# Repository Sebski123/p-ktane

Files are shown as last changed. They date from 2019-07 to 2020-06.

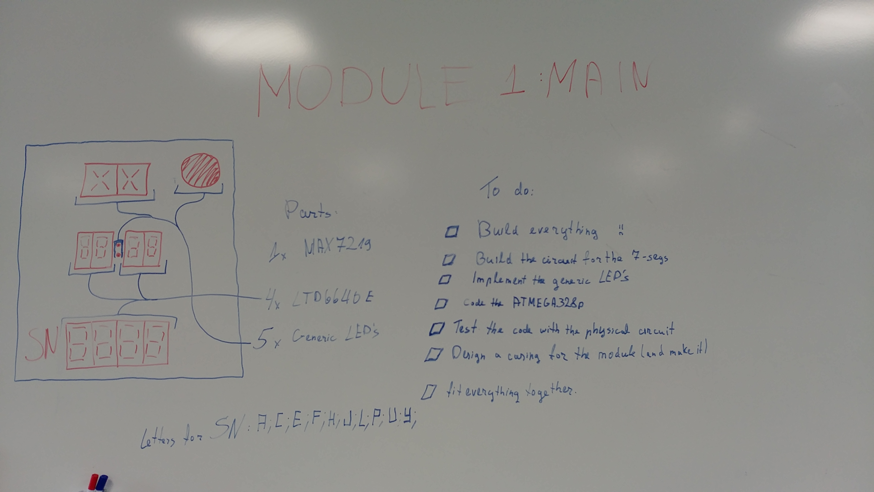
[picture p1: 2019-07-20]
Modules/mainModule/mainModule.jpg

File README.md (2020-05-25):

# P-KTANE
## Sources
* https://github.com/dlareau/KTANE-physical
* https://imgur.com/gallery/J6HdM0v
* https://old.reddit.com/r/ktane/comments/a3fgyt/i_made_a_physical_version_of_the_video_game_keep/
* https://github.com/jgillick/avr-discobus

## Modules
| Module | Coded | Built | Tested | I2C addr |
|---|---|---|---|---|
| Main (Controller) | ✔️ | | | MASTER |
| Config (ESP8266) | ✔️ | ✔️ | ✔️ | 2 |
| [Wires](https://i.imgur.com/xLXpCYH.png) | ✔️ | ✔️ | ✔️ | 3 |
| [Button](https://i.imgur.com/Leew7du.png) | ✔️ | | | 4 |
| [Keypads](https://i.imgur.com/Zy6ScEo.png) | | | | |
| [Simon Says](https://i.imgur.com/uX7BzED.png) | ✔️ | ✔️ | | 5 |
| [Who's on First](https://i.imgur.com/YisE1go.png) | | | | |
| [Memory](https://i.imgur.com/bvGt5gz.png) | ✔️ | ✔️ | | 6 |
| [Morse Code](https://i.imgur.com/V4XAdVZ.png) | | | | |
| [Complicated Wires](https://i.imgur.com/jJb2Kp9.png) | | | | |
| [Wire Sequences](https://i.imgur.com/1drzKTO.png) | | | | |
| [Mazes](https://i.imgur.com/xXMdvLr.png) | ✔️ | ✔️ | ✔️ | 7 |
| [Passwords](https://i.imgur.com/us0XRBs.png) | ✔️ | | | |
| [Venting Gas](https://i.imgur.com/f2eua3p.png) | | | | |
| [Capacitor Discharge](https://i.imgur.com/Q0VJkoo.png) | | | | |
| [Knobs](https://i.imgur.com/hlpkEUD.png) | | | | |

# How to burn bootloader and upload sketches for ATMega328
## How to burn bootloader
### Install boards
1. Open the Arduino IDE.
1. Open the **File > Preferences** menu item.
1. Enter the following URL in **Additional Boards Manager URLs**:

    ```
    https://mcudude.github.io/MiniCore/package_MCUdude_MiniCore_index.json
    ``` 

1. Open the **Tools > Board > Boards Manager...** menu item.
1. Wait for the platform indexes to finish downloading.
1. Scroll down until you see the **MiniCore** entry and click on it.
1. Click **Install**.
1. After installation is complete close the **Boards Manager** window.
1. **Note**: If you plan to use the *PB series, you need the latest version of the Arduino toolchain. This toolchain is available through IDE 1.8.6 or newer. Here's how you install/enable the toolchain:
  -  Open the **Tools > Board > Boards Manager...** menu item.
  -  Wait for the platform indexes to finish downloading.
  -  The top is named **Arduino AVR boards**. Click on this item.
  -  Make sure the latest version is installed and selected
  -  Close the **Boards Manager** window.

### Prepare Arduino
1. Copy [this](https://raw.githubusercontent.com/adafruit/ArduinoISP/master/ArduinoISP.ino) code into the Arduino IDE and upload it to an Arduino normally.
1. Connect Arduino to the ATMega as shown below (Capacitor is important).


### Burn bootloader
1. Select the **Tools > Board > ATmega328** menu item from the MiniCore section.
1. Select the **Tools > Variant > 328 / 328A** menu item.
1. Select the **Tools > Clock > Internal 8MHz** menu item.
1. Select the **Tools > Programmer > Arduino as ISP** menu item.
1. Click **Tools > Burn Bootloader**

## How to upload sketches
### Wiring
1. Remove ATmega328 from Arduino
1. Connect Arduino to the ATMega as shown below.


### Uploading
1. Select the **Tools > Board > ATmega328** menu item from the MiniCore section.
1. Select the **Tools > Variant > 328 / 328A** menu item.
1. Select the **Tools > Clock > Internal 8MHz** menu item.
1. Select the **Tools > Programmer > Arduino as ISP** menu item.
1. Click Upload.

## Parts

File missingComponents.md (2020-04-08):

- Pinheaders-4 x6
- Pinheaders-5 x6
- Pins-4 x6
- 100nF Cap x8
- 10uF Pol Cap x2
- 24.5k Res x4
- Big 7-segment x2
- 0.1 uF Cap x2
- Max7219 x4
- Simon says button x4
- 10k Res x13
- 1k Res x6
- ATMEGA328 x6
- Double 7-segment x6
- 330 Res x21
- RGB LEDs x7
- Push-Buttons x12
- Single pin-header x12
- Green LED x42
- Red LED x4 
- Big transparent button (3D-print)
- Keyboard switches x~5
- Small speaker
- 16-segment x7

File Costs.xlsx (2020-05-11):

Item | Url | Cost | Payee
Transparent 3D-printing filament | https://www.computersalg.dk/i/1127597/verbatim-gennemsigtig-1-kg-abs | 196 | Sebastian
Digikey Order | http://www.digikey.dk | 415.95 | Sebastian
Digikey Order Import Tax | http://www.digikey.dk | 104 | Sebastian
AliExpress simon says switches | https://www.aliexpress.com/item/32833573067.html?spm=a2g0s.9042311.0.0.412d4c4dSjG8y1 | 116 | Sebastian
Total paid by Sebastian: | 831.95
Total paid by Laurynas: | 0
 |  | 415.975 | PAID

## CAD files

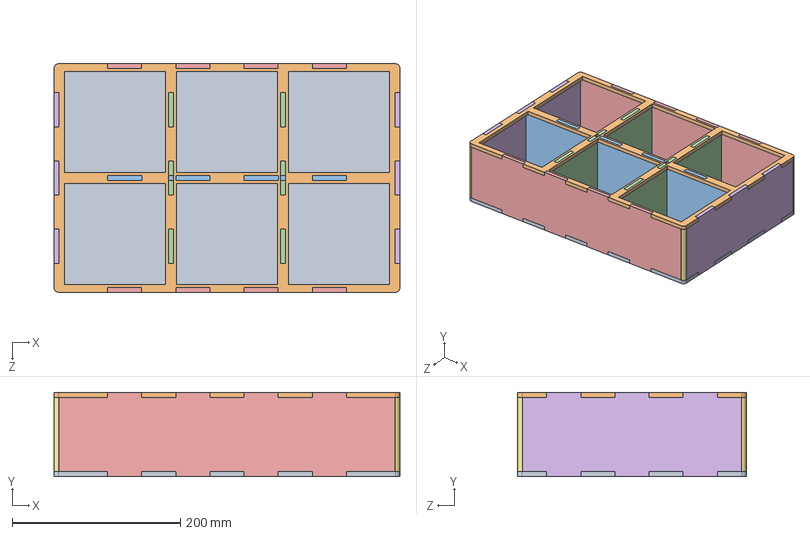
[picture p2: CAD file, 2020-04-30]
Design/Box/Box.SLDASM
410.8 x 100.0 x 271.4 mm
BoxBottom
BoxTop
InsideLarge
InsideSmall x 2
SidesLarge x 2
SidesSmall x 2
Corner x 4

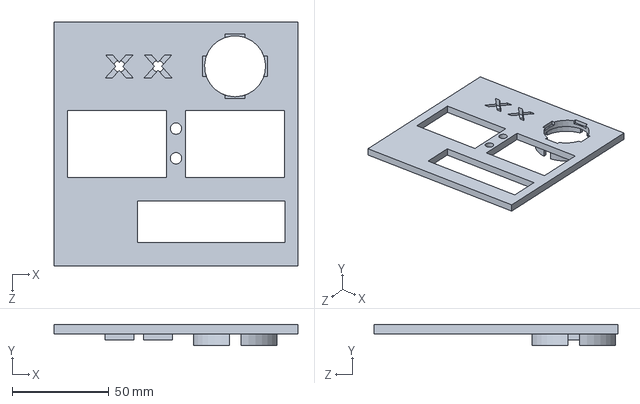
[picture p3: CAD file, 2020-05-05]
Modules/mainModule/Main face plate.SLDPRT
126.0 x 11.0 x 126.0 mm

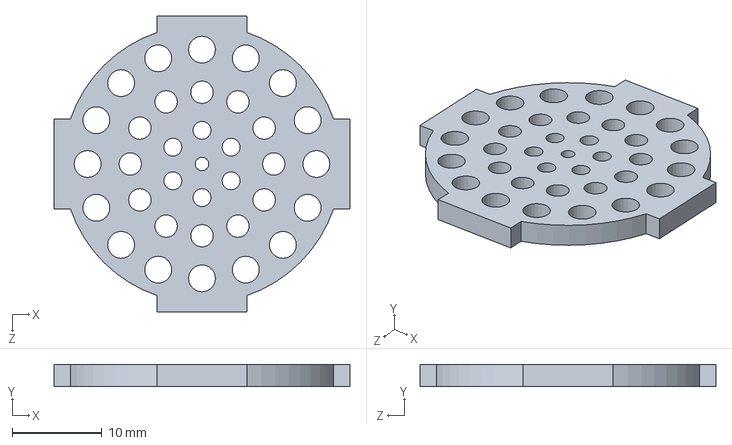
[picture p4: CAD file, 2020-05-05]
Modules/mainModule/Main face plate grill.SLDPRT
33.0 x 2.50 x 33.0 mm

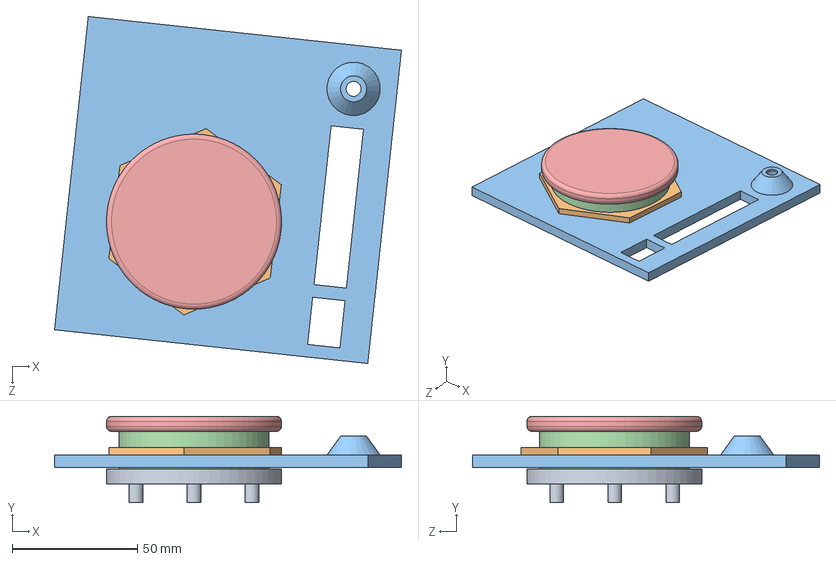
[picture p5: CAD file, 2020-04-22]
Modules/buttonModule/ButtonAssembly.SLDASM
138.8 x 34.5 x 138.8 mm
Button base
Button face plate ring
Button face plate
Button middle
Button top

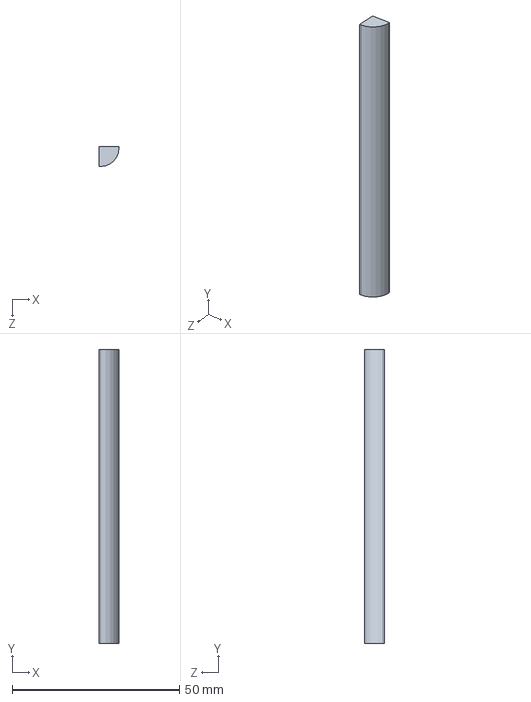
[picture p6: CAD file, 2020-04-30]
Design/Box/Box parts/Corner.SLDPRT
6.00 x 88.0 x 6.00 mm

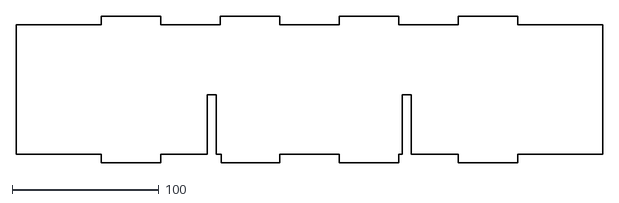
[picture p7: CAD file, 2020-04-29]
Design/Box/DXF FILES/InsideLarge.dxf
398.7 x 100.0

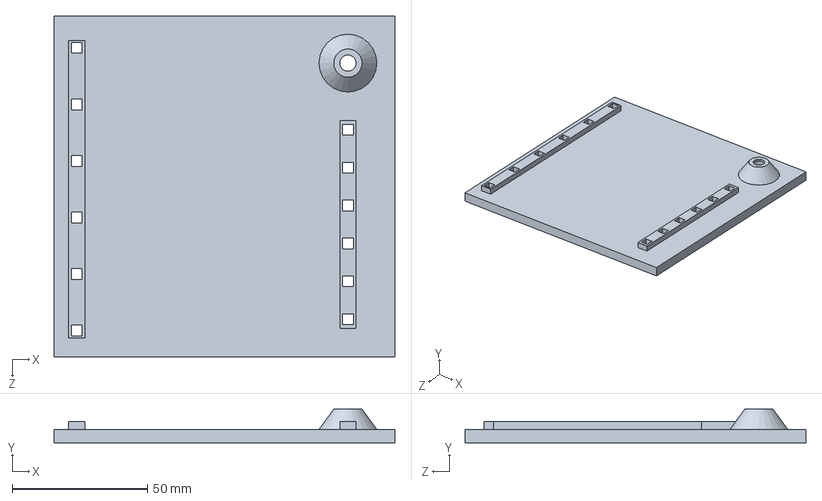
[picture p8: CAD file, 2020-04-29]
Modules/basicWiresModule/Wire face plate.SLDPRT
126.0 x 12.5 x 126.0 mm

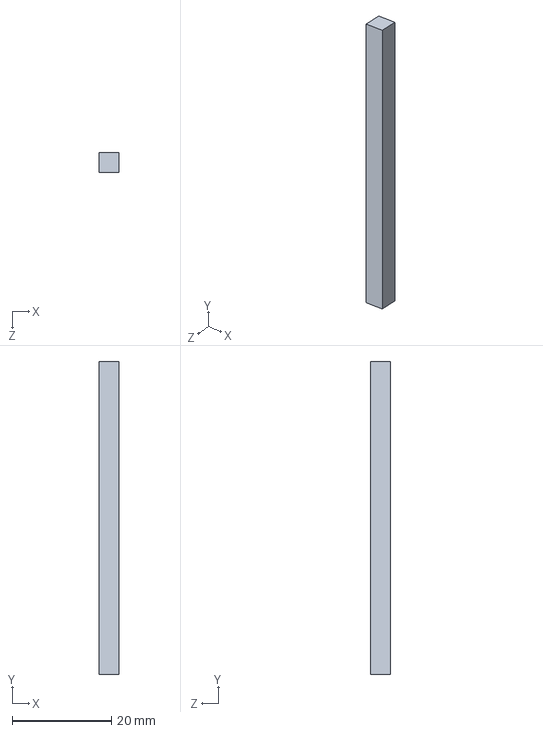
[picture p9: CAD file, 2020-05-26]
Modules/buttonModule/MXFramePillar.SLDPRT
4.00 x 63.0 x 4.00 mm

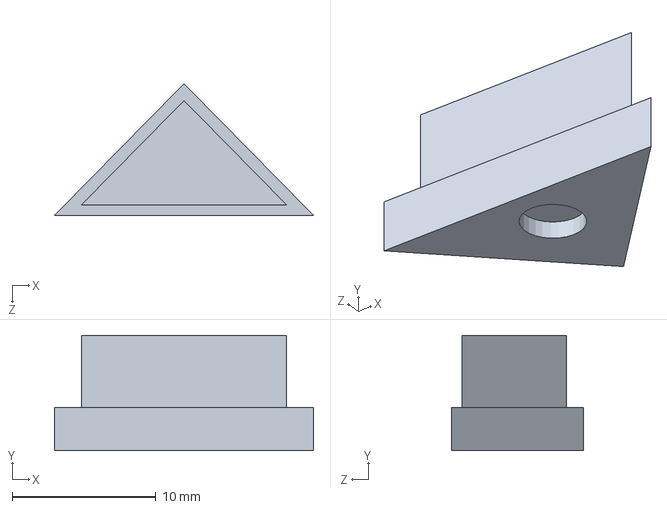
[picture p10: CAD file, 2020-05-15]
Modules/mazeModule/Maze button.SLDPRT
18.0 x 8.00 x 9.15 mm

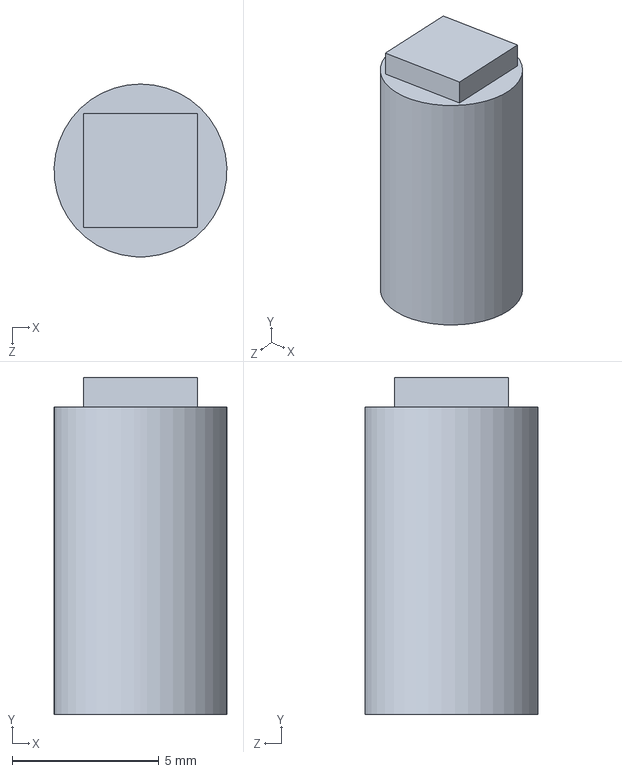
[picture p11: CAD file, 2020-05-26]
Modules/memoryModule/Memory button top.SLDPRT
5.90 x 11.5 x 5.90 mm

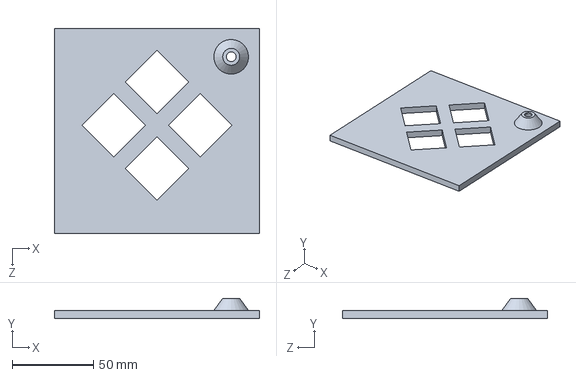
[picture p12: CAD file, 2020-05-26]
Modules/simonSaysModule/Simon says face plate.SLDPRT
126.0 x 12.5 x 126.0 mm

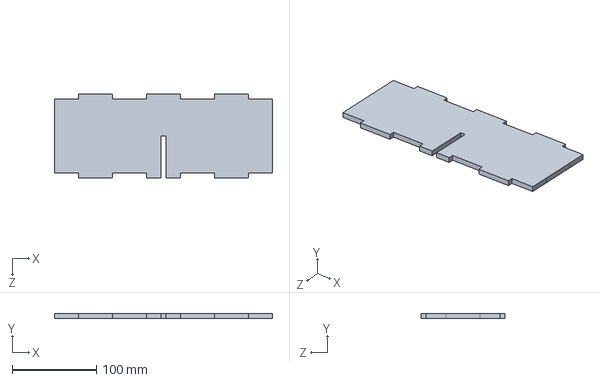
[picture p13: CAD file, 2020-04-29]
Design/Box/Box parts/InsideSmall.SLDPRT
259.4 x 6.00 x 100.0 mm

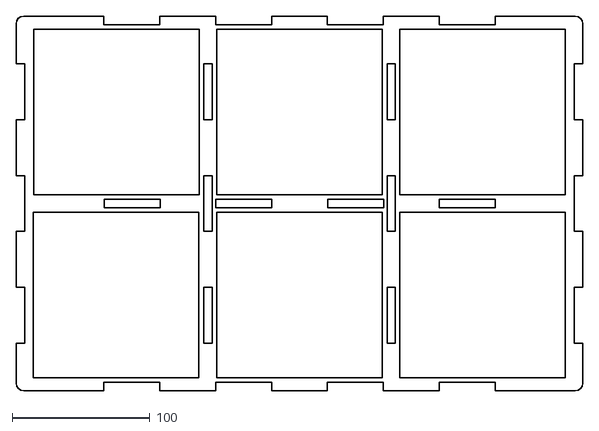
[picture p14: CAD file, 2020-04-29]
Design/Box/DXF FILES/BoxTop.dxf
410.7 x 271.4

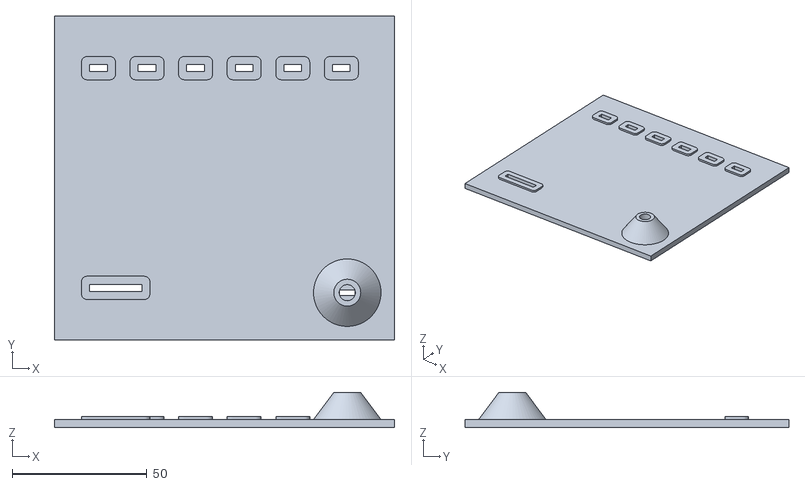
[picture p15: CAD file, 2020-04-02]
Modules/basicWiresModule/front_plate_wires.stl
126.0 x 120.0 x 13.0

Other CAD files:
Modules/buttonModule/MXFrameBottom.SLDPRT
Modules/mazeModule/Maze face plate.SLDPRT
Modules/memoryModule/TRIANGLE.SLDPRT
Modules/simonSaysModule/front_plate_simon.stp
Design/Box/Box parts/BoxBottom.SLDPRT
Design/Box/Box parts/BoxTop.SLDPRT
Design/Box/Box parts/InsideLarge.SLDPRT
Design/Box/Box parts/SidesLarge.SLDPRT
Design/Box/Box parts/SidesSmall.SLDPRT
Design/Box/DXF FILES/BoxBottom.dxf
Design/Box/DXF FILES/InsideSmall.dxf
Design/Box/DXF FILES/SidesLarge.dxf
Design/Box/DXF FILES/SidesSmall.dxf
Modules/buttonModule/Button base.SLDPRT
Modules/buttonModule/Button face plate ring.SLDPRT
Modules/buttonModule/Button face plate side bar.SLDPRT
Modules/buttonModule/Button face plate.SLDPRT
Modules/buttonModule/Button middle.SLDPRT
Modules/buttonModule/Button top.SLDPRT
Modules/buttonModule/MXFrameTop.SLDPRT
Modules/buttonModule/MXSwitchLegs.SLDPRT
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

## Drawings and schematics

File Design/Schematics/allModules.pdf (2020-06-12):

C5 R⁴ | R³ | R² | R¹ | R⁵

# 5 CN8 R⁴⁹

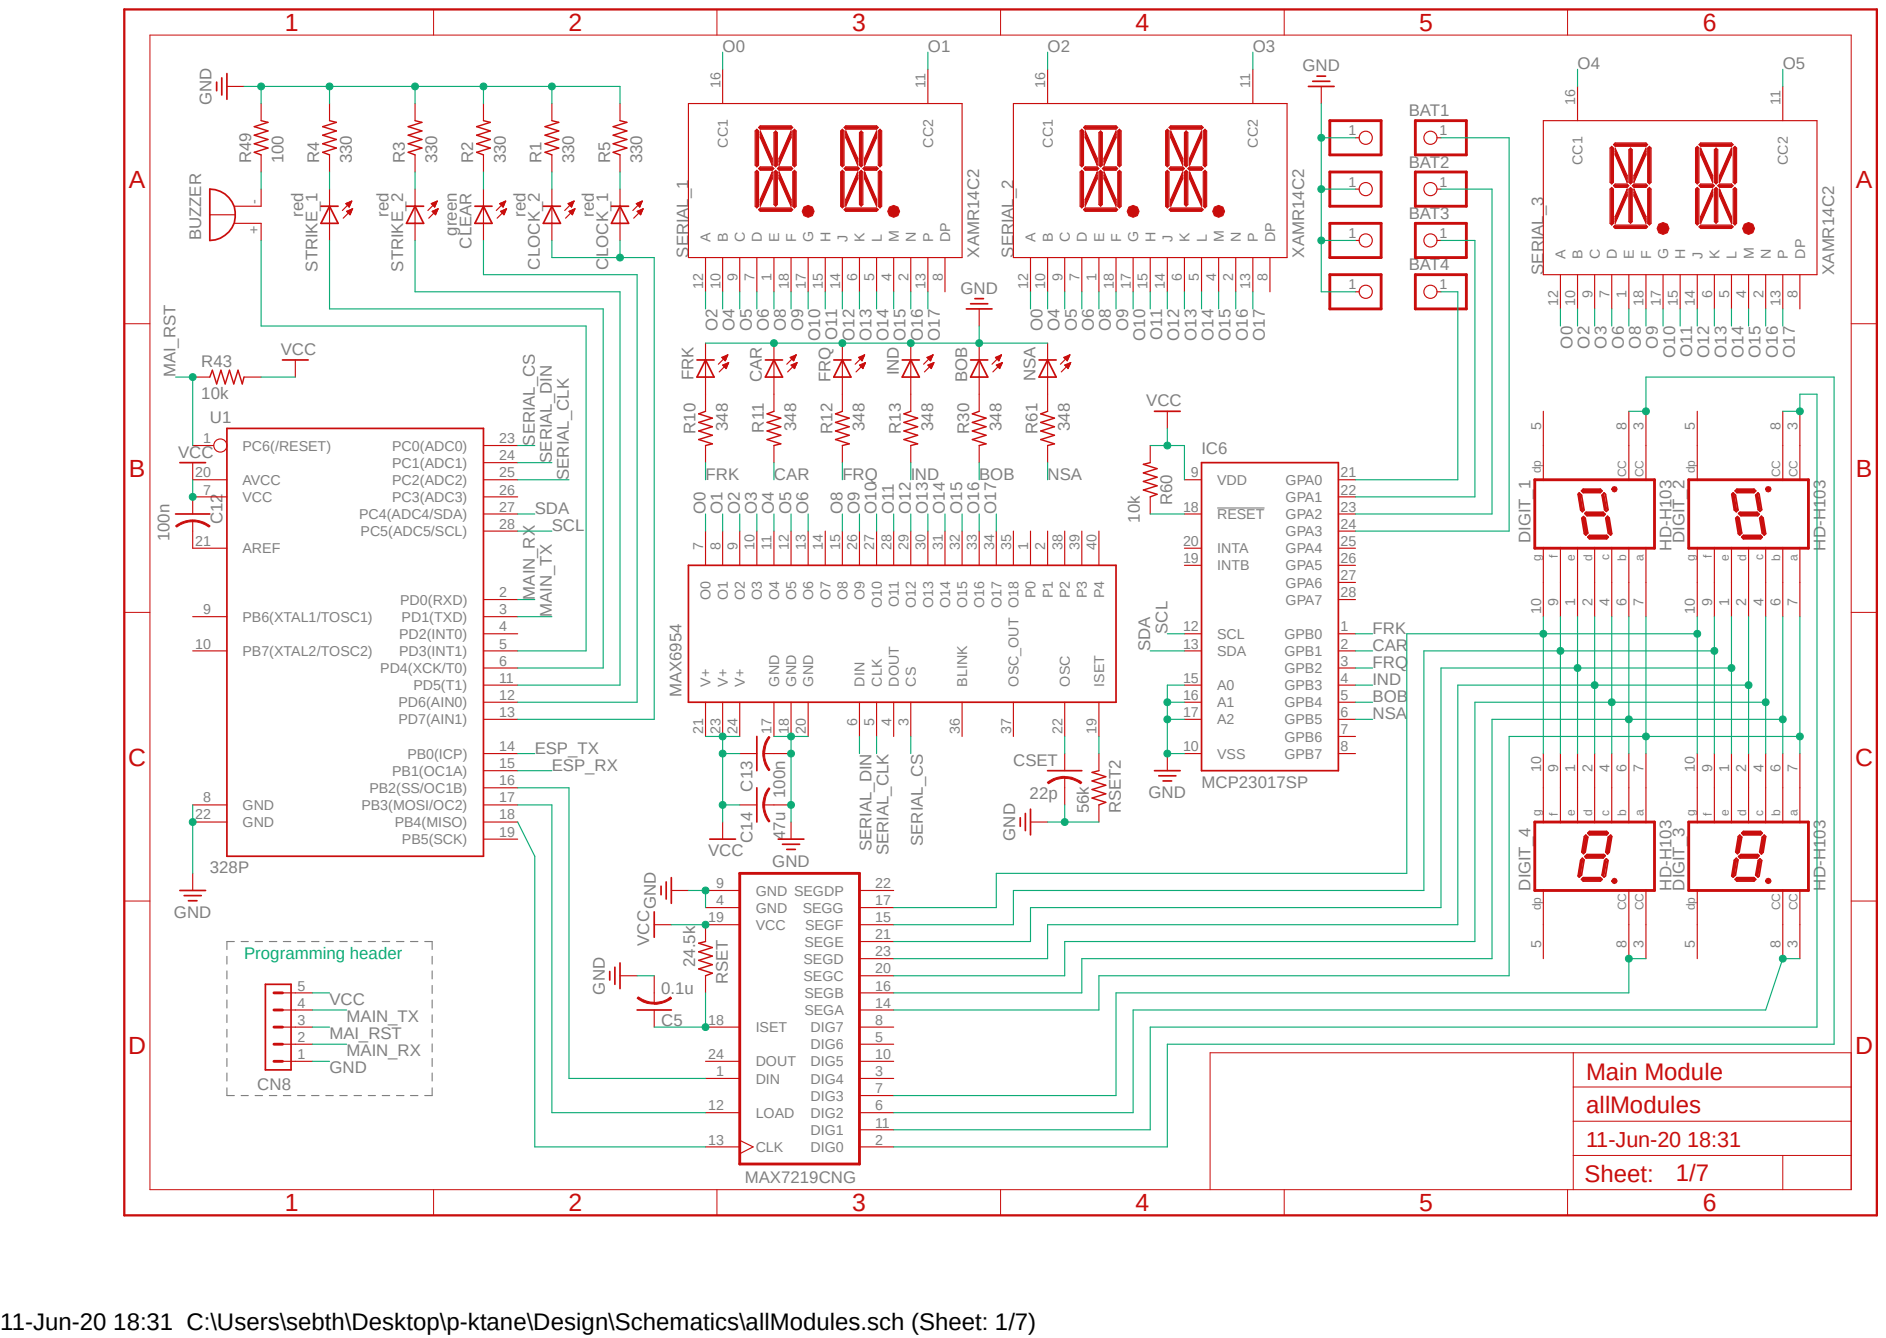
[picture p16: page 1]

11-Jun-20 18:31 C:\Users\sebth\Desktop\p-ktane\Design\Schematics\allModules.sch (Sheet: 1/7)

A

A

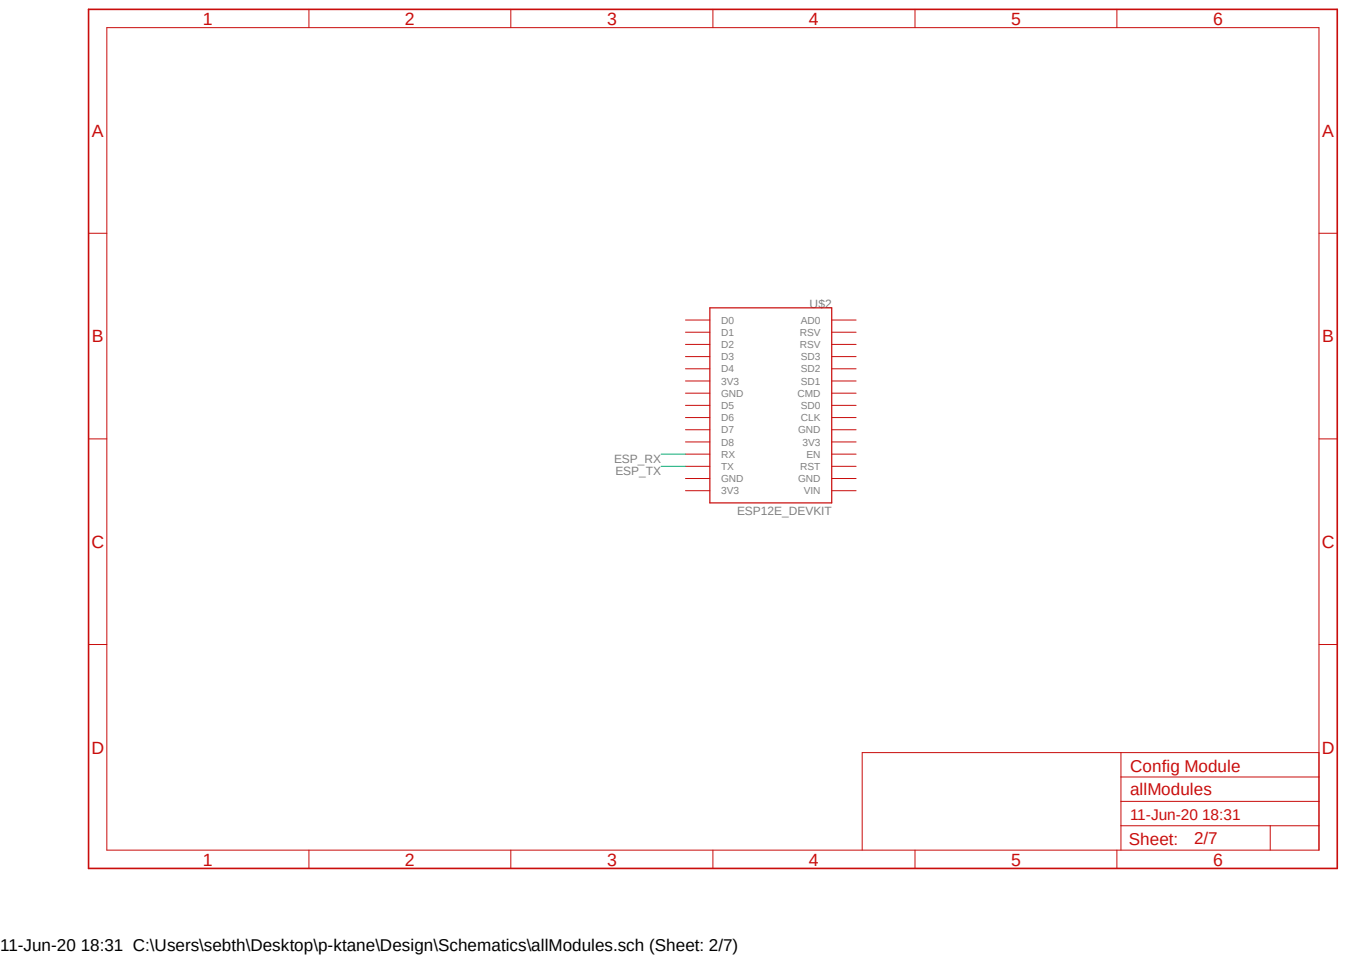
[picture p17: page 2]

11-Jun-20 18:31 C:\Users\sebth\Desktop\p-ktane\Design\Schematics\allModules.sch (Sheet: 2/7)

A

A

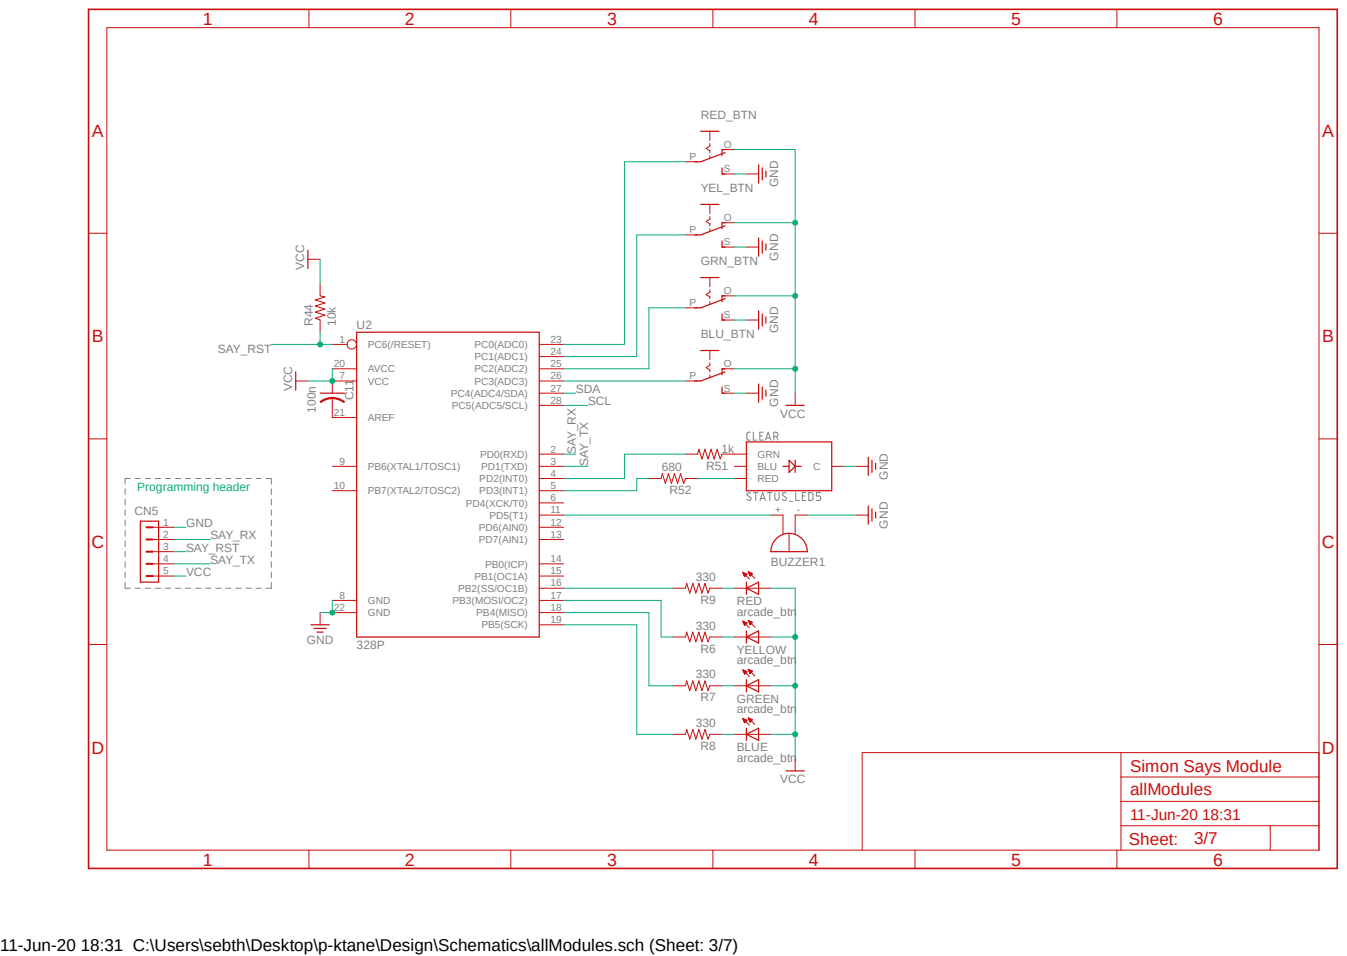
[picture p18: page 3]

arcade_btn GND GND GND GNDVCC

11-Jun-20 18:31 C:\Users\sebth\Desktop\p-ktane\Design\Schematics\allModules.sch (Sheet: 3/7)

GND 1k | 680
5 CN4 C¹⁰ R⁴⁵ | GRN BLU C RED R⁵³ | R⁵⁴

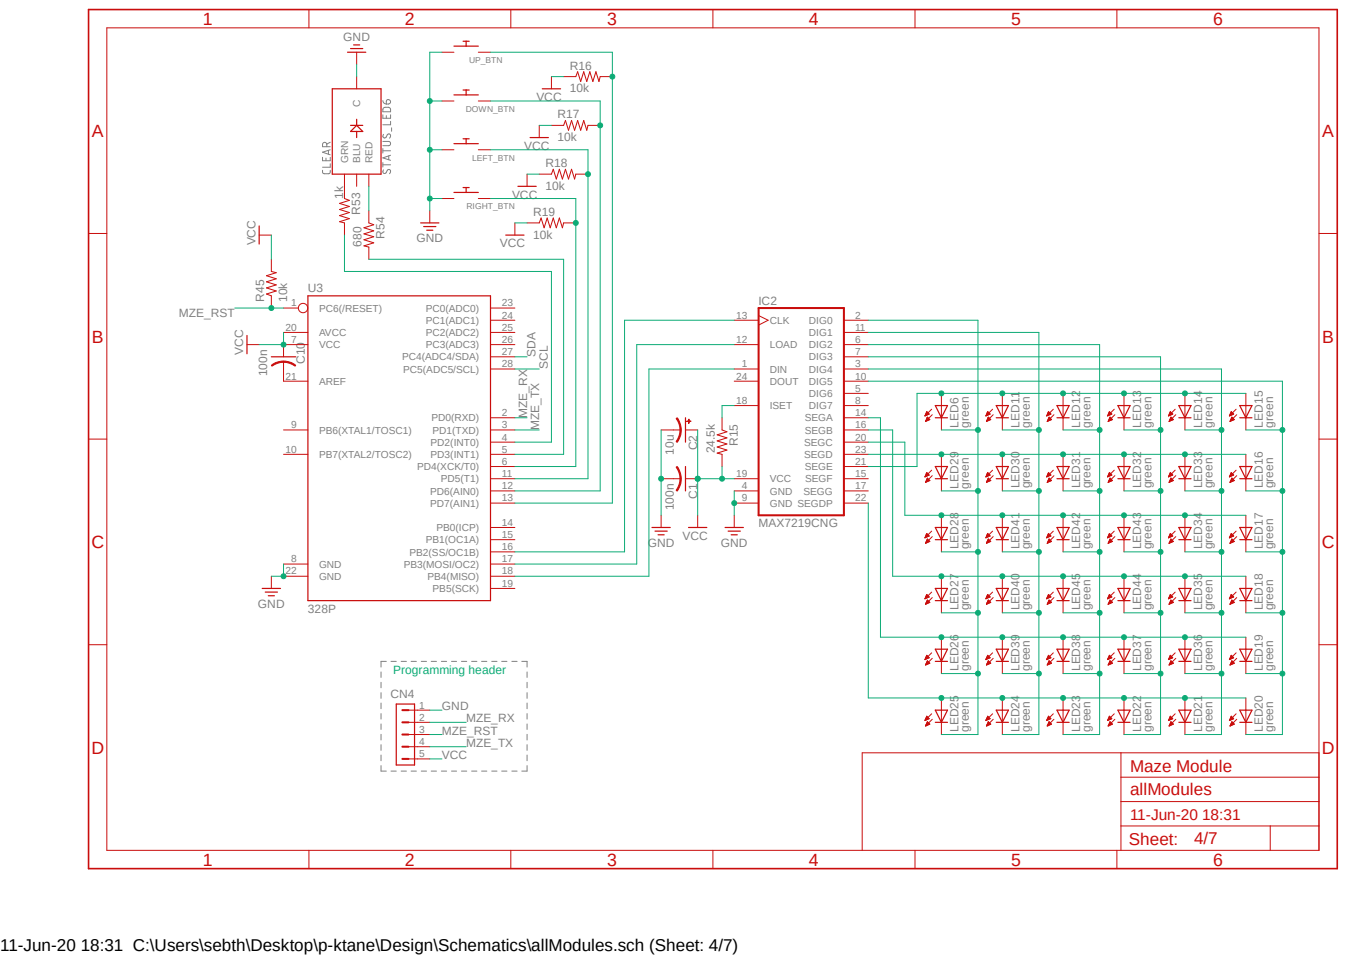
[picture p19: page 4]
MAX7219CNG; GND; GND VCC VCC; VCC; green; green green green green green green green green green green; green green; green green green green green green; green 100n; 10k VCC; DIG2; DIG3; DIG4; DIG5; DIG6; DIG7; SEGA; SEGB; SEGC; SEGD; SEGE; SEGF; SEGG; SEGDP; DIG1; 11 DIG0; DIN 1 DOUT 24; LOAD 12; CLK 13; ISET 18; GND 9; GND 4; VCC 19; PB5(SCK); PB7(XTAL2/TOSC2) 10; PB6(XTAL1/TOSC1) 9; GND 8 GND 22; VCC 7; AREF 21; AVCC 20; PB4(MISO); 18 PB3(MOSI/OC2); 15 PB0(ICP); PD7(AIN1); 13 PD6(AIN0)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

11-Jun-20 18:31 C:\Users\sebth\Desktop\p-ktane\Design\Schematics\allModules.sch (Sheet: 4/7)

# 5 CN3 R⁴⁶

# SW_TX SW_RST

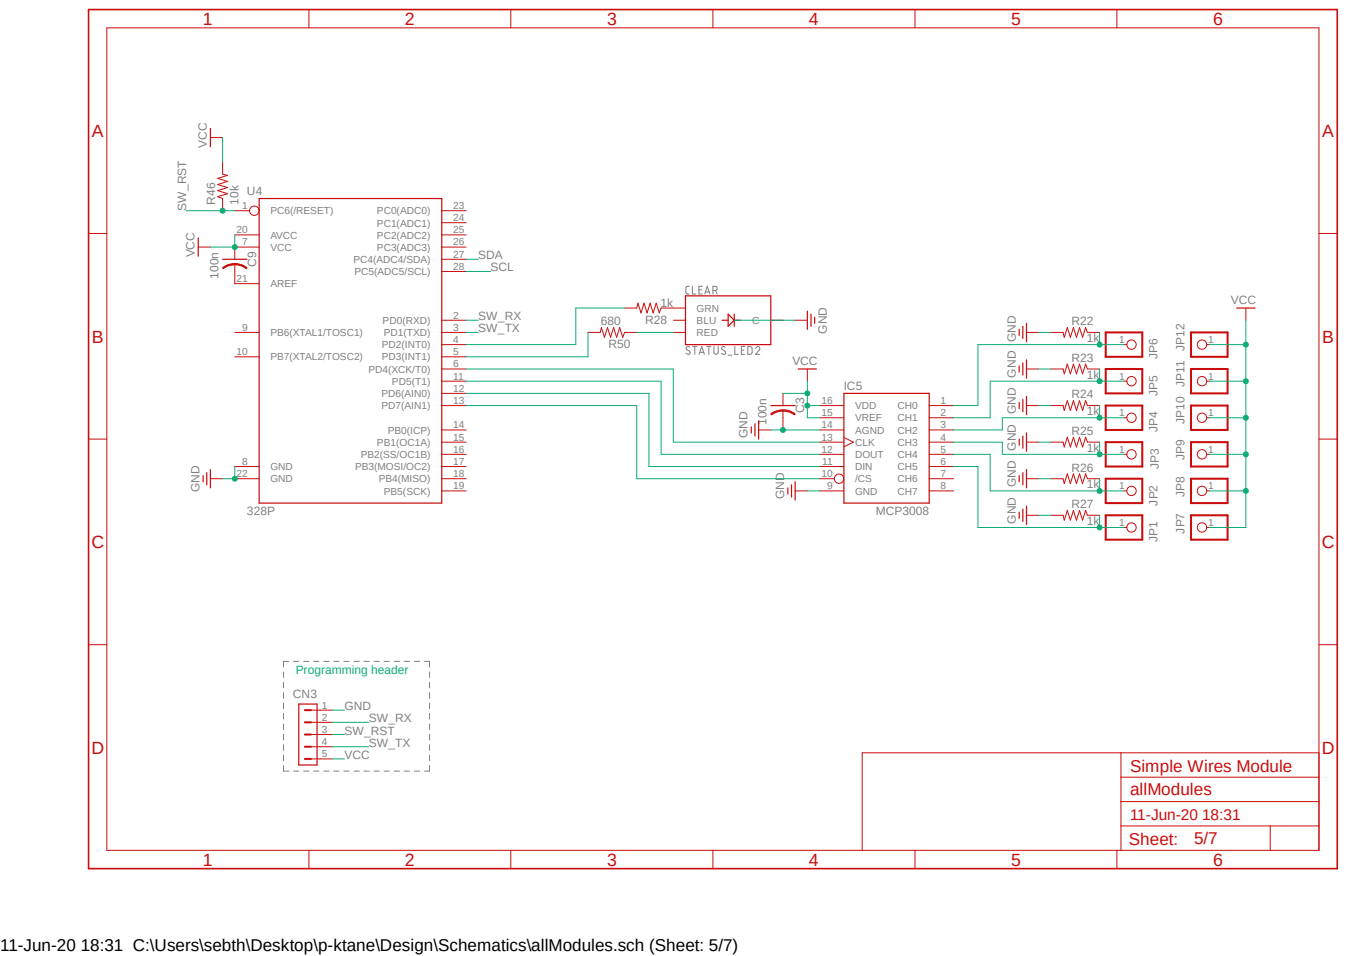
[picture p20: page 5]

11-Jun-20 18:31 C:\Users\sebth\Desktop\p-ktane\Design\Schematics\allModules.sch (Sheet: 5/7)

# 5 CN2 C⁸ R⁴⁷

A

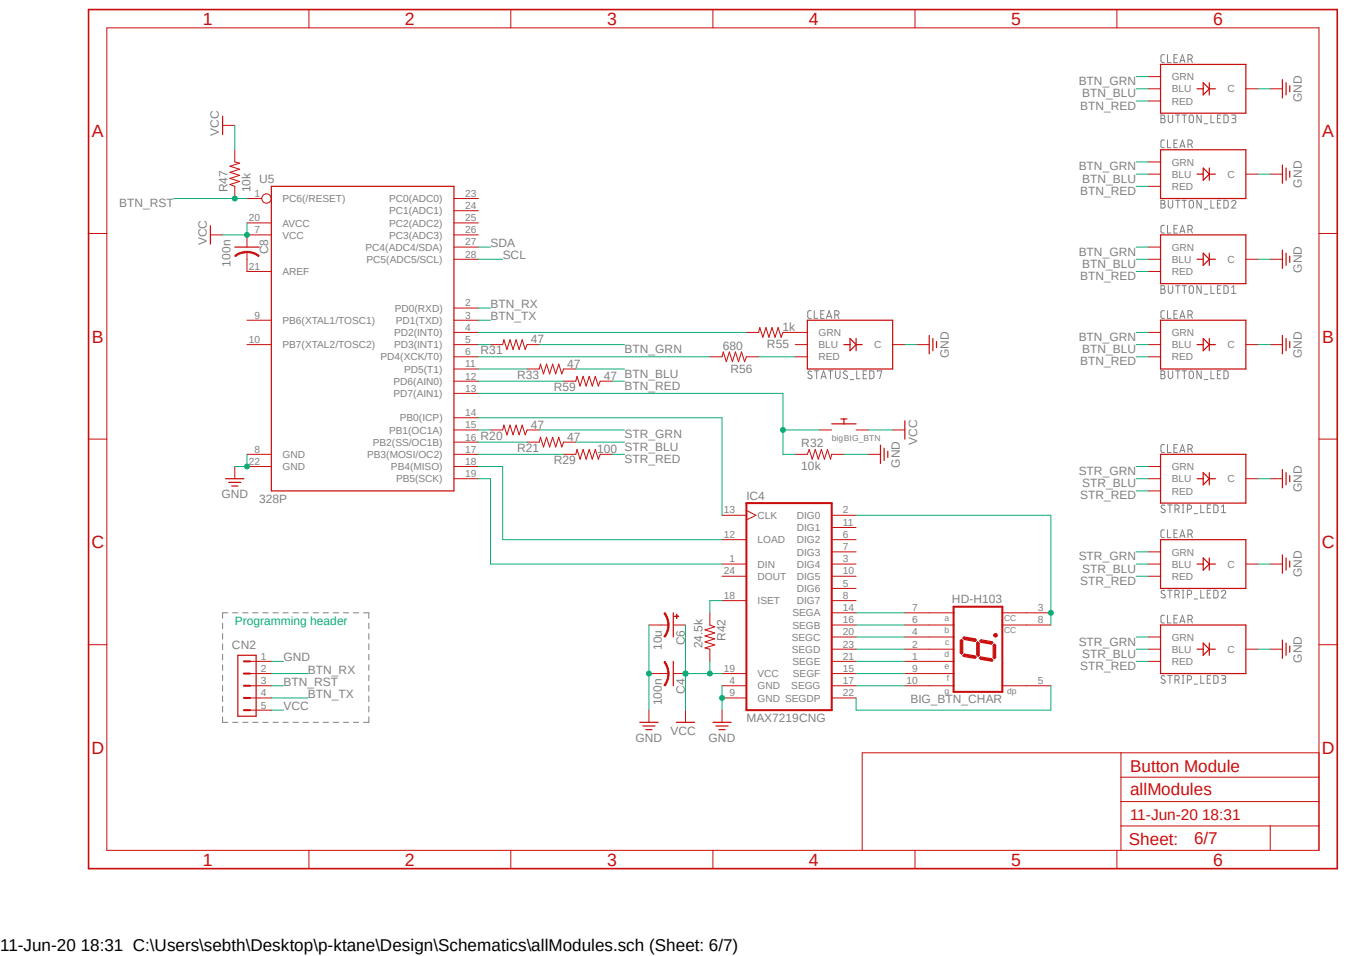
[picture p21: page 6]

11-Jun-20 18:31 C:\Users\sebth\Desktop\p-ktane\Design\Schematics\allModules.sch (Sheet: 6/7)

VCC | MEM_RX
MEM_RX | MEM_TX

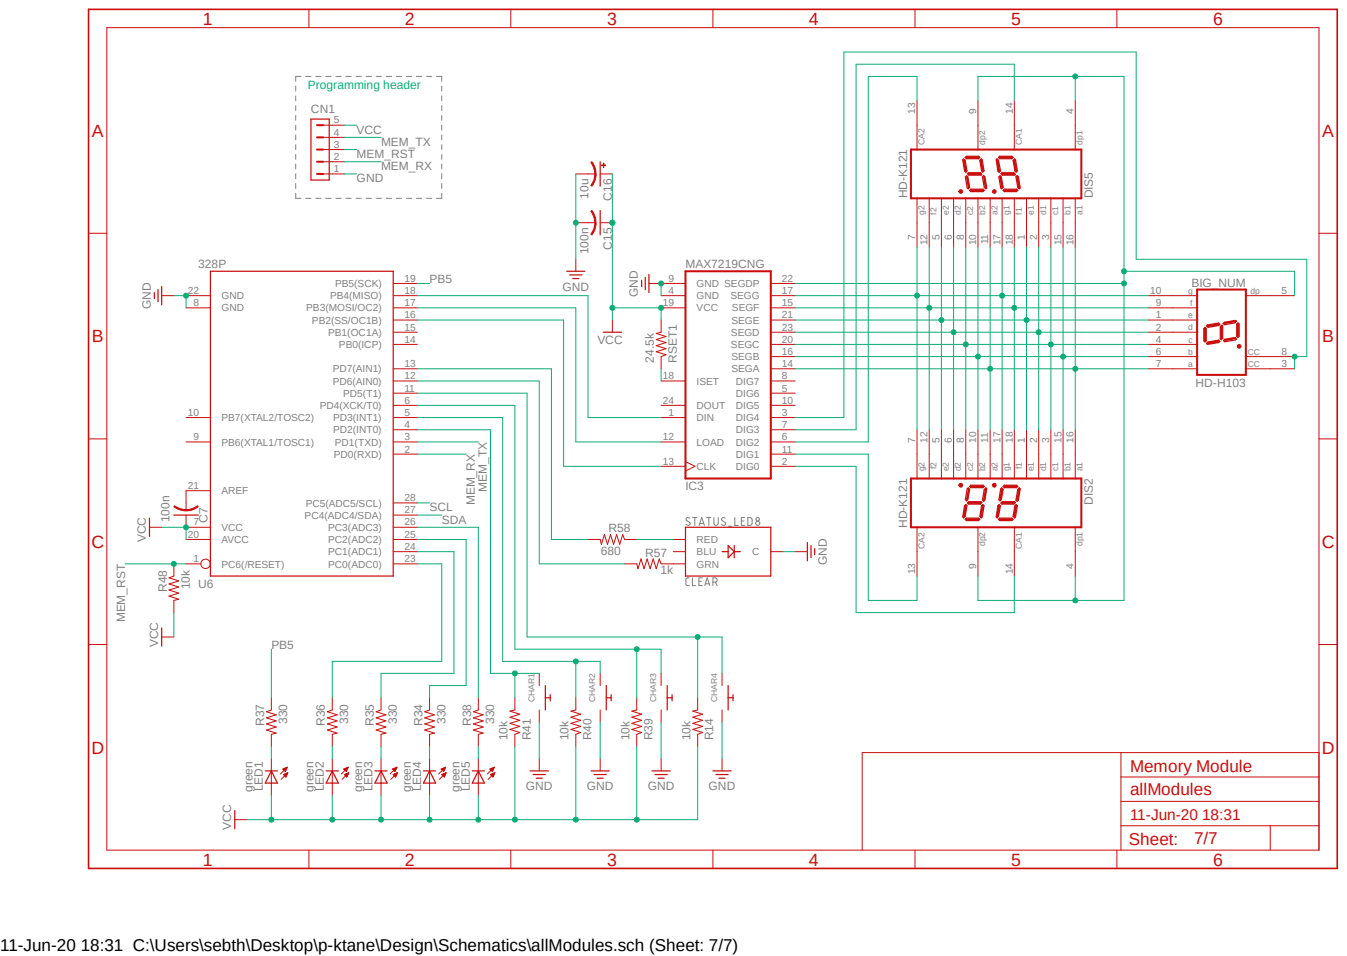
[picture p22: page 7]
328P GND VCC; MAX7219CNG 24.5k GND; HD⁻K¹²¹ HD⁻K¹²¹; HD-H103 green; green; GND; GND VCC; 330 100n 10k VCC; VCC; PB5(SCK); PB7(XTAL2/TOSC2) 10; PB6(XTAL1/TOSC1) 9; GND 8; GND 22; VCC 7; AREF 21; AVCC 20; PB4(MISO); PB3(MOSI/OC2); PB0(ICP); PD7(AIN1); PD6(AIN0); PD4(XCK/T0); PD3(INT1); PD2(INT0); PD1(TXD); PD0(RXD); PC5(ADC5/SCL); PC4(ADC4/SDA); PC3(ADC3); PC2(ADC2); PC1(ADC1); PC0(ADC0); 23 PC6(/RESET) 1U6; DIG2; DIG3; DIG4; DIG5; 10 DIG6; DIG7; SEGA; 14 SEGB; 16 SEGC; 20 SEGD; 23 SEGE; 21 SEGF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

2 d
4 c
6 b

11-Jun-20 18:31 C:\Users\sebth\Desktop\p-ktane\Design\Schematics\allModules.sch (Sheet: 7/7)

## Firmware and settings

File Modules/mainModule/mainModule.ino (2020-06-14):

#include "SWire.h"
#include "KTANECommon.h"
#include "LedControl.h"
#include "MAX6954.h"
#include "Adafruit_MCP23017.h"
#include <SoftwareSerial.h>

// Defines
//  Pins
#define SPEAKER_PIN 3
#define STRIKE_1_PIN 4
#define STRIKE_2_PIN 5
#define CLEAR_PIN 6
#define CLOCK_DOT 7
#define CONF_RX 8
#define CONF_TX 9
#define CLOCK_DATA 10
#define CLOCK_LOAD 11
#define CLOCK_CLK 12
#define SERIAL_CS 14
#define SERIAL_DATAOUT 15
#define SERIAL_CLK 16
//I2C SDA 18
//I2C SCL 19
//  I/O Expander pins
#define BATT1 0
#define BATT2 1
#define BATT3 2
#define BATT4 3
#define FRK_LED 8
#define CAR_LED 9
#define FRQ_LED 10
#define IND_LED 11
#define BOB_LED 12
#define NSA_LED 13

//Class init
Adafruit_MCP23017 mcp;
SoftwareSerial configSerial = SoftwareSerial(CONF_RX, CONF_TX);
MAX6954 serialnr = MAX6954(SERIAL_DATAOUT, SERIAL_CLK, SERIAL_CS);
LedControl clock = LedControl(CLOCK_DATA, CLOCK_CLK, CLOCK_LOAD, 1);
config_t config;
SWireMaster master;
KTANEController controller(master);

//Variables
int brightness = 4;
int win_melody[] = {262, 330, 294, 370, 392};
int win_melody_durations[] = {8, 8, 8, 8, 2};
int win_melody_len = 5;
int lose_melody[] = {659, 622, 587, 554};
int lose_melody_durations[] = {8, 8, 8, 1};
int lose_melody_len = 4;
int num_minutes;
unsigned long currentMillis;
unsigned long previousMillis = 0;
unsigned long count = 0;
unsigned long diff_time = 0;
byte msClockCount = 0;

//  Globals
int strikes = 0;
int solves = 0;
unsigned long dest_time;
int num_modules;
uint8_t clients[16];

void toggleClockBlink()
{
  digitalWrite(CLOCK_DOT, !digitalRead(CLOCK_DOT));
}

void playMelody(int *melody, int *durations, int melody_len)
{
  for (int thisNote = 0; thisNote < melody_len; thisNote++)
  {

    int noteDuration = 1000 / durations[thisNote];
    tone(SPEAKER_PIN, melody[thisNote], noteDuration);

    // to distinguish the notes, set a minimum time between them.
    int pauseBetweenNotes = noteDuration * 1.30;
    delayWithUpdates(controller, pauseBetweenNotes);

    // stop the tone playing:
    noTone(SPEAKER_PIN);
  }
}

void youLose()
{
  // Play lose music
  Serial.println("Loose");
  if (diff_time < 1000)
  {
    clock.setDigit(0, 0, 0, false);
    clock.setDigit(0, 1, 0, false);
    clock.setDigit(0, 2, 0, false);
    clock.setDigit(0, 3, 0, false);
  }

  serialnr.write_string(" boom ");
  playMelody(lose_melody, lose_melody_durations, lose_melody_len);

  // Stop clock
  while (1)
  {
    delayWithUpdates(controller, 10);
  }
}

void youWin()
{
  int seconds = (diff_time / 1000) % 60;
  int minutes = diff_time / 60000;
  // Play win music
  Serial.println("Win");

  digitalWrite(CLEAR_PIN, HIGH);

  serialnr.write_string("winner");
  playMelody(win_melody, win_melody_durations, win_melody_len);

  configSerial.write('W');
  configSerial.write((char)((minutes / 10) + '0'));
  configSerial.write((char)((minutes % 10) + '0'));
  configSerial.write((char)((seconds / 10) + '0'));
  configSerial.write((char)((seconds % 10) + '0'));

  // Stop clock
  while (1)
  {
    delayWithUpdates(controller, 10);
  }
}

void getConfigESP()
{
  raw_config_t recv_config;

  configSerial.write("1");
  while (configSerial.available() <= 0)
  {
    delay(10);
  }
  for (int i = 0; i < 7; i++)
  {
    ((char *)(&recv_config))[i] = configSerial.read();
  }
  num_minutes = configSerial.read();
  raw_to_config(&recv_config, &config);
}

void getConfigManual()
{
  config.ports = 3;
  config.batteries = 1;
  config.indicators = 0;
  strncpy(config.serial, "123456", 6);
  config.serial[6] = '\0';
  num_minutes = 6;
}

void setup()
{
#pragma region Serial setup
  Serial.begin(19200);
  configSerial.begin(19200);

  while (!Serial)
  {
    ;
  } // wait for serial port to connect. Needed for native USB
  while (!configSerial)
  {
    ;
  } // wait for serial port to connect. Needed for native USB

#pragma endregion

#pragma region Get config
  Serial.println("Getting config");
  getConfigESP();
  //getConfigManual();
  Serial.println("Got config");
#pragma endregion

#pragma region I / O Expander setup
  mcp.begin(); // use default address 0x20

  //Setup battery pins and enable 100K internal pullup 
  mcp.pinMode(BATT1, INPUT);
  mcp.pinMode(BATT2, INPUT);
  mcp.pinMode(BATT3, INPUT);
  mcp.pinMode(BATT4, INPUT);
  mcp.pullUp(BATT1, HIGH);
  mcp.pullUp(BATT2, HIGH);
  mcp.pullUp(BATT3, HIGH);
  mcp.pullUp(BATT4, HIGH);

  //Setup indicator pins
  mcp.pinMode(FRK_LED, OUTPUT);
  mcp.pinMode(CAR_LED, OUTPUT);
  mcp.pinMode(FRQ_LED, OUTPUT);
  mcp.pinMode(IND_LED, OUTPUT);
  mcp.pinMode(BOB_LED, OUTPUT);
  mcp.pinMode(NSA_LED, OUTPUT);
#pragma endregion

#pragma region SET / GET I / O Expander values
  //Read number of batteries
  config.batteries = 0;
  for(int i = 0; i < 4; i++){
    config.batteries += !mcp.digitalRead(i);
  }
  
  config.indicators = 0;
  randomSeed(config_to_seed(&config));

  // Turn on indicators randomly
  for(int i = 8; i < 14; i++){
    mcp.digitalWrite(i, random(2));
  }

  //Read FRK and CAR indicators
  config.indicators |= mcp.digitalRead(FRK_LED);
  config.indicators |= (mcp.digitalRead(CAR_LED) << 1);
#pragma endregion

#pragma region Show config
  Serial.print("Serial nr. : ");
  Serial.println(config.serial);
  Serial.print("No. of Batteries: ");
  Serial.println(config.batteries);
  Serial.print("Lit indicators: ");
  if (config.indicators & 1)
  {
    Serial.print("FRK\t");
  }
  if (config.indicators & 2)
  {
    Serial.print("CAR");
  }
  Serial.println();
  Serial.print("Ports: ");
  if (config.ports & 1)
  {
    Serial.print("Parallel\t");
  }
  if (config.ports & 2)
  {
    Serial.print("RJ45\t");
  }
  if (config.ports & 4)
  {
    Serial.print("RCA");
  }
  Serial.println();
  Serial.print("Minutes to beat: ");
  Serial.println(num_minutes);
  Serial.println();

  delay(100);
#pragma endregion

#pragma region I / O setup
  Serial.println("Setting up I/O-pins");
  // LED/Speaker setup
  pinMode(STRIKE_1_PIN, OUTPUT);
  pinMode(STRIKE_2_PIN, OUTPUT);
  pinMode(CLEAR_PIN, OUTPUT);
  pinMode(CLOCK_DOT, OUTPUT);
  pinMode(SPEAKER_PIN, OUTPUT);

  digitalWrite(STRIKE_1_PIN, LOW);
  digitalWrite(STRIKE_2_PIN, LOW);
  digitalWrite(CLEAR_PIN, LOW);

#pragma endregion

#pragma region Display setup
  Serial.println("Initializing display");
  /*
   The MAX72XX is in power-saving mode on startup,
   we have to do a wakeup call
   */
  serialnr.begin();
  clock.shutdown(0, false);
  /* Set the brightness to a medium values */
  serialnr.set_global_brightness(8);
  clock.setIntensity(0, 8);
  /* and clear the display */
  clock.clearDisplay(0);
  serialnr.clear();

  delay(500);
#pragma endregion

#pragma region Serial setup
  Serial.println("Writing serial-number");
  // Serial alphanumeric setup
  serialnr.write_string(config.serial);

  delay(1000);
#pragma endregion

  Serial.println("Get modules");
  num_modules = master.identifyClients();

  Serial.print("Number of modules: ");
  Serial.println(num_modules);

  Serial.print("Client id's: ");
  master.getClients(clients);
  for (size_t i = 0; i < num_modules; i++)
  {
    Serial.print(clients[i]);
    Serial.print("\t");
  }
  Serial.println();

#pragma region Prepare modules
  controller.sendReset();
  delayWithUpdates(controller, 1000);
  Serial.println("Sending config to clients");
  int test = controller.sendConfig(&config);
  Serial.println(test);
  while (!controller.clientsAreReady())
  {
    controller.interpretData();
  }

  Serial.println("Clients are ready");
#pragma endregion

  dest_time = millis() + (long)num_minutes * 60 * 1000;
  controller.setTime(dest_time);

  Serial.println("Done setup");
}

void loop()
{
  //Serial.println("Getting data");
  controller.interpretData();

  currentMillis = millis();

  diff_time = dest_time - millis();

  if (diff_time > 60000)
  {
    if (currentMillis - previousMillis >= 500)
    {
      // save the last time you blinked the LED
      previousMillis = currentMillis;
      //Serial.println("blink");
      // if the LED is off turn it on and vice-versa:
      toggleClockBlink();

      // Update clock

      controller.setTime(diff_time);
      int seconds = (diff_time / 1000) % 60;
      int minutes = diff_time / 60000;
      clock.setDigit(0, 0, (minutes / 10), false);
      clock.setDigit(0, 1, (minutes % 10), false);
      clock.setDigit(0, 2, (seconds / 10), false);
      clock.setDigit(0, 3, (seconds % 10), false);
    }
  }
  else
  {
    if (currentMillis - previousMillis >= 10)
    {
      // save the last time you blinked the LED
      previousMillis = currentMillis;
      //Serial.println("blink");
      // if the LED is off turn it on and vice-versa:
      if (msClockCount > 25)
      {
        toggleClockBlink();
        msClockCount = 0;
      }
      else
      {
        msClockCount++;
      }
      // Update clock

      controller.setTime(diff_time);
      int seconds = (diff_time / 1000) % 60;
      int millisecs = diff_time - (seconds * 1000);
      clock.setDigit(0, 0, (seconds / 10), false);
      clock.setDigit(0, 1, (seconds % 10), false);
      clock.setDigit(0, 2, (millisecs / 10), false);
      clock.setDigit(0, 3, (millisecs % 10), false);
    }
  }
  if (millis() > dest_time)
  {
    youLose();
  }

  if (strikes < controller.getStrikes())
  {
    tone(SPEAKER_PIN, 340, 150);
    delayWithUpdates(controller, 200);
    tone(SPEAKER_PIN, 140, 150);
    delayWithUpdates(controller, 150);
    noTone(SPEAKER_PIN);
    strikes = controller.getStrikes();
    Serial.println("STRIKE!");
    Serial.println(strikes);
  }

  if (solves < controller.getSolves())
  {
    tone(SPEAKER_PIN, 140, 150);
    delayWithUpdates(controller, 200);
    tone(SPEAKER_PIN, 340, 150);
    delayWithUpdates(controller, 150);
    noTone(SPEAKER_PIN);
    solves = controller.getSolves();
  }

  digitalWrite(STRIKE_1_PIN, strikes >= 1);
  digitalWrite(STRIKE_2_PIN, strikes >= 2);

  if (strikes >= 3)
  {
    youLose();
  }

  if (controller.getSolves() >= num_modules)
  {
    youWin();
  }
}

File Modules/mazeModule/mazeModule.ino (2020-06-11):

#include "SWire.h"
#include "KTANECommon.h"
#include "LedControl.h"
#include "mazeModule.h"

// Defines
//  Pins
#define GREEN_CLEAR_LED 2
#define RED_STRIKE_LED 3
#define RIGHT_BTN 4
#define UP_BTN 5
#define DOWN_BTN 6
#define LEFT_BTN 7
#define CLOCK_PIN 10
#define LOAD_PIN 11
#define DATA_PIN 12
//I2C SDA 18
//I2C SCL 19

//Class inits
LedControl lc = LedControl(DATA_PIN, CLOCK_PIN, LOAD_PIN, 1);
SWireClient client(0x07);
KTANEModule module(client, GREEN_CLEAR_LED, RED_STRIKE_LED);


//Variables
int playerLocation[2];
int goalLocation[2];
byte markerLocations[2][2];
int mazeNum;
bool markerBlinkState = true;
bool playerBlinkState = true;
unsigned long currentMillis;
unsigned long previousMarkerMillis = 0;
unsigned long previousPlayerMillis = 0;
int dir;
int markerBlinkCount = 0;
unsigned long lastDebounceTime = 0; // the last time the output pin was toggled


int getBtnDir()
{
  if (digitalRead(UP_BTN) == 0)
  {
    return UP;
  }
  else if (digitalRead(DOWN_BTN) == 0)
  {
    return DOWN;
  }
  else if (digitalRead(LEFT_BTN) == 0)
  {
    return LEFT;
  }
  else if (digitalRead(RIGHT_BTN) == 0)
  {
    return RIGHT;
  }
  else
  {
    return -1;
  }
}

void move(int direction)
{
  Serial.print("Trying to move ");

  switch (direction)
  {

  case UP:
    Serial.println(F("up"));
    if (mazeHorizontalWalls[mazeNum][playerLocation[0]][playerLocation[1]])
    {
      module.strike();
      Serial.println(F("Strike"));
    }
    else
    {
      lc.setLed(0, playerLocation[0], playerLocation[1], false);
      playerLocation[1] -= 1;
      lc.setLed(0, playerLocation[0], playerLocation[1], playerBlinkState);
    }
    break;

  case DOWN:
    Serial.println(F("down"));
    if (mazeHorizontalWalls[mazeNum][playerLocation[0]][playerLocation[1] + 1])
    {
      module.strike();
      Serial.println(F("Strike"));
    }
    else
    {
      lc.setLed(0, playerLocation[0], playerLocation[1], false);
      playerLocation[1] += 1;
      lc.setLed(0, playerLocation[0], playerLocation[1], playerBlinkState);
    }
    break;

  case LEFT:
    Serial.println(F("left"));
    if (mazeVerticalWalls[mazeNum][playerLocation[1]][playerLocation[0]])
    {
      module.strike();
      Serial.println(F("Strike"));
    }
    else
    {
      lc.setLed(0, playerLocation[0], playerLocation[1], false);
      playerLocation[0] -= 1;
      lc.setLed(0, playerLocation[0], playerLocation[1], playerBlinkState);
    }
    break;

  case RIGHT:
    Serial.println(F("right"));
    if (mazeVerticalWalls[mazeNum][playerLocation[1]][playerLocation[0] + 1])
    {
      module.strike();
      Serial.println(F("Strike"));
    }
    else
    {
      lc.setLed(0, playerLocation[0], playerLocation[1], false);
      playerLocation[0] += 1;
      lc.setLed(0, playerLocation[0], playerLocation[1], playerBlinkState);
    }
    break;

  default:
    break;
  }
  return;
}

void setup()
{
  Serial.begin(19200);

  Serial.println(F("Getting config"));
  while (!module.getConfig())
  {
    module.interpretData();
  }
  Serial.println(F("Got config"));

  Serial.println(F("Setting random seed"));
  randomSeed(config_to_seed(module.getConfig()));

  Serial.println(F("Setting up I/O-pins"));
  // 8x8 Led-matrix setup
  pinMode(DATA_PIN, OUTPUT);
  pinMode(CLOCK_PIN, OUTPUT);
  pinMode(LOAD_PIN, OUTPUT);

  //Directional-buttons setup
  pinMode(UP_BTN, INPUT_PULLUP);
  pinMode(DOWN_BTN, INPUT_PULLUP);
  pinMode(LEFT_BTN, INPUT_PULLUP);
  pinMode(RIGHT_BTN, INPUT_PULLUP);

  /*
   The MAX72XX is in power-saving mode on startup,
   we have to do a wakeup call
   */
  lc.shutdown(0, false);
  /* Set the brightness to a medium values */
  lc.setIntensity(0, 8);
  /* and clear the display */
  lc.clearDisplay(0);

  Serial.println(F("Choosing maze"));
  mazeNum = random(0, 9);
  Serial.println(F("Choose maze nr: "));
  Serial.println(mazeNum);

  Serial.println(F("Getting marker locations"));
  memcpy(markerLocations, markers[mazeNum], sizeof(markerLocations));
  Serial.print(F("Marker 1 location: "));
  Serial.print(markerLocations[0][0]);
  Serial.print("\t");
  Serial.println(markerLocations[0][1]);

  Serial.print(F("Marker 2 location: "));
  Serial.print(markerLocations[1][0]);
  Serial.print("\t");
  Serial.println(markerLocations[1][1]);

  Serial.println(F("Choosing player location"));
  playerLocation[0] = random(0, 6);
  playerLocation[1] = random(0, 6);
  Serial.println(F("Player location: "));
  Serial.print(playerLocation[0]);
  Serial.print("\t");
  Serial.println(playerLocation[1]);

  Serial.println(F("Choosing goal location"));
  do
  {
    goalLocation[0] = random(0, 6);
    goalLocation[1] = random(0, 6);
  } while (
      ((goalLocation[0] == playerLocation[0])     && (goalLocation[1] == playerLocation[1]))      ||
      ((goalLocation[0] == markerLocations[0][0]) && (goalLocation[1] == markerLocations[0][1]))  ||
      ((goalLocation[0] == markerLocations[1][0]) && (goalLocation[1] == markerLocations[1][1]))  ||
      (abs((goalLocation[0] - playerLocation[0]) + (goalLocation[1] - playerLocation[1])) < 5));

  Serial.println(F("Goal location: "));
  Serial.print(goalLocation[0]);
  Serial.print("\t");
  Serial.println(goalLocation[1]);

  Serial.println(F("Showing goal location"));
  lc.setLed(0, goalLocation[0], goalLocation[1], true);

  Serial.println(F("Setup done"));
  module.sendReady();
}

void loop()
{
  module.interpretData();

  if (!module.is_solved)
  {
    //Blink maze markers and player location with different intervals
    currentMillis = millis();

    if (currentMillis - previousPlayerMillis >= 100)
    {
      // save the last time you blinked the player
      if (markerBlinkCount >= 5)
      {
        markerBlinkState = !markerBlinkState;
        markerBlinkCount = 0;
      }
      else
      {
        markerBlinkCount++;
      }

      previousPlayerMillis = currentMillis;
      playerBlinkState = !playerBlinkState;

      lc.setLed(0, markerLocations[0][0], markerLocations[0][1], markerBlinkState);
      lc.setLed(0, markerLocations[1][0], markerLocations[1][1], markerBlinkState);
      lc.setLed(0, playerLocation[0], playerLocation[1], playerBlinkState);
    }


    if (millis() - lastDebounceTime >= 200)
    {

      //Read button press
      dir = getBtnDir();
      if (dir >= 0)
      {
        lastDebounceTime = millis();
        Serial.print(F("Pressed: "));
        Serial.println(dir);

        //Try to move the player, gave a strike if a wall is hit
        move(dir);

        Serial.println(F("Player location: "));
        Serial.print(playerLocation[0]);
        Serial.print("\t");
        Serial.println(playerLocation[1]);
      }
    }
    //Check if player reached the goal
    if ((playerLocation[0] == goalLocation[0]) && (playerLocation[1] == goalLocation[1]))
    {
      module.win();
      Serial.println(F("Win"));
    }
  }
}

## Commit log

2019-07-20 Added the schematics for the main module
    [Main_module_scheme.sch]
2019-07-24 Added a module schematics folder and added the updated schematics to it
    [Module scheme.sch]
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2019-07-24 Added maze module schematics
    [Module scheme.sch]
2019-07-27 Renamed dir and .cpp file
    [Main_module_scheme.sch]
2019-08-02 Renamed some files
    [mainModule.sch]
2019-08-02 Moved and renamed some files
    [allModules.sch]
2019-08-02 Deleted duplicate file
    [mainModule.sch]
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2019-08-12 Added names to some of the components
    [allModules.sch]
2019-08-15 fixed some stuff in the schematic
    [allModules.sch]
2019-08-15 Fixing some pin numbers
    [mainModule.ino, mazeModule.ino]
2019-08-15 Finished maze Module schematic
    [allModules.sch]
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2020-04-02 Added basic wires module
    [front_plate_wires.stl, front_plate_wires.stp]
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2020-04-02 Added SimonSays 3d files
    [front_plate_simon.stl, front_plate_simon.stp]
2020-04-02 Added memory module including 3d files
    [front_plate_memory.stl, front_plate_memory.stp]
2020-04-02 Fixed includes and now updates time for other modules to access
    [mainModule.ino]
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2020-04-07 Made code match schematics
    [allModules.sch]
2020-04-07 Added debug headers and module interconnections
    [allModules.sch]
2020-04-08 Added part file for button base
    [Button_base.SLDPRT]
2020-04-08 Added part file for button middle
    [Button_middle.SLDPRT]
2020-04-08 Added part file for button top
    [Button_top.SLDPRT]
2020-04-08 Fix css on setup page
    [configModule.ino]
2020-04-08 Fixed formatting and added some debug messages
    [basicWires.ino]
2020-04-08 Fixed formatting and added debugging via. SWSerial
    [mainModule.ino]
2020-04-09 Added template for module face plate
    [Basic_face_plate.SLDPRT]
2020-04-09 Remade wire module face plate, should be more like the game now
    [Wire_face_plate.SLDPRT]
2020-04-09 Added prototype for button face plate, not finalized yet
    [Button_face_plate.SLDPRT]
2020-04-10 Resized the button files, will now fit the face plate
    [Button base.SLDPRT, Button middle.SLDPRT, Button top.SLDPRT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]
2020-04-10 Updated face plate, added ring part. Still need to make outer case for button
    [Button face plate ring.SLDPRT, Button face plate.SLDPRT, Button_face_plate.SLDPRT]
2020-04-11 Added spreadsheet for calculating expenses
    [Costs.xlsx]
2020-04-12 Fixed issue of dest_time overflowing
    [mainModule.ino]
2020-04-12 Now keeps showing time left when bomb is solved
    [mainModule.ino]
2020-04-12 Added frames to all modules
    [allModules.sch]
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2020-04-12 Revert "Added frames to all modules"
    This reverts commit 3eabf43de3682e49b345895a8346113ada920e34
    [allModules.sch]
2020-04-13 Updated button face plate with cutouts for LEDs under button
    [Button face plate.SLDPRT]
2020-04-14 Modified existing face plates with wider spacings
    [Basic face plate.SLDPRT, Basic_face_plate.SLDPRT, Button face plate ring.SLDPRT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]
2020-04-14 Added face plate for memory module, buttons included
    [Memory button base.SLDPRT, Memory button top.SLDPRT, Memory face plate.SLDPRT]
2020-04-22 Modified button module, now has LEDs built into the button
    [Basic face plate.SLDPRT, Button base.SLDPRT, Button face plate.SLDPRT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]
2020-04-22 Changed wire face plate to the correct file
    [Basic face plate.SLDPRT, Wire face plate.SLDPRT]
2020-04-22 changed button face plate to correct file
    [Basic face plate.SLDPRT, Button face plate.SLDPRT]
2020-04-22 Added assembly for button module
    [ButtonAssembly.SLDASM, front_plate_wires.stp]
2020-04-26 Fixed issue with red and black wires being swaped and added more logging
    [basicWires.ino]
2020-04-27 Added super early prototype of box design
    [Box prototype.SLDPRT]
2020-04-29 Added finished design of box
    [Box prototype.SLDPRT]
2020-04-29 Added solidworks files for each box part
    [BoxBottom.SLDPRT, BoxTop.SLDPRT, InsideLarge.SLDPRT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]
2020-04-29 Added DXF files of all box parts
    [BoxBottom.dxf, BoxTop.dxf, InsideLarge.dxf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]
2020-04-29 Updated wire face plate with larger holes
    [Wire face plate.SLDPRT]
2020-04-29 Added assembly for box
    [Box.SLDASM]
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2020-04-30 Added corner piece to box and updated the assembly
    [Box.SLDASM, Corner.SLDPRT]
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2020-04-30 Fixed some inputs being inverted and added logging
    [simonSays.ino]
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2020-05-04 Updated schematic to add serial displays
    [allModules.sch]
2020-05-05 Added main module face plate and speaker grill
    [Main face plate grill.SLDPRT, Main face plate.SLDPRT]
2020-05-05 Added file for button face plate side bar
    [Button face plate side bar.SLDPRT]
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2020-05-11 Added missing wire to maze module
    [allModules.sch]
2020-05-11 Fixed red and black being swapped and added some logging
    [basicWires.ino]
2020-05-11 Fixed issue where it was detecting false positives
    [basicWires.ino]
2020-05-13 Added face plate for maze module
    [Maze face plate.SLDPRT]
2020-05-14 Fixed victory condition as well as a small type error
    [mazeModule.ino]
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2020-05-14 No longer clears entire display every frame
    [mazeModule.ino]
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2020-05-14 Updated maze module face plate with bigger spacings
    [Maze face plate.SLDPRT]
2020-05-15 Added file for maze button
    [Maze button.SLDPRT]
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2020-05-17 Change schematic to accurately reflect how clear leds work
    [allModules.sch]
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2020-05-18 Added buzzer to simon says module
    [allModules.sch]
2020-05-18 Added buzzer code to simon says
    [simonSays.ino]
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2020-05-20 Fixed buttons being inverted
    [memory.ino]
2020-05-20 Swapped "up" and "left" buttons
    [mazeModule.ino]
2020-05-20 Removed infinite loop that prevented module from being restarted
    [mazeModule.ino]
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2020-05-21 Updated button base to have replacable legs
    [Button base.SLDPRT, MXSwitchLegs.SLDPRT]
2020-05-21 Added files for button module support
    [MXFrameBottom.SLDPRT, MXFramePillar.SLDPRT, MXFrameTop.SLDPRT]
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2020-05-25 Updated memory schematic to I2C
    [allModules.sch]
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2020-05-25 Fixed issue with display not clearing
    [memory.ino]
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2020-05-25 Updated modules for I2C and added external ADC for wires module
    [allModules.sch]
2020-05-25 Swapped 2 pins and added mising class init
    [button.ino]
2020-05-26 updated pillar for button holder
    [MXFramePillar.SLDPRT]
2020-05-26 Updated spacings for memory module face plate
    [Memory face plate.SLDPRT]
2020-05-26 Update all modules to use I2C
    [allModules.sch]
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2020-05-26 Added power connections for wires module
    [allModules.sch]
2020-05-26 Added face plate design for simon says module
    [Simon says face plate.SLDPRT]
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2020-05-26 Added connection betwen main module and config module
    [allModules.sch]
2020-05-26 Increased length of stem
    [Memory button top.SLDPRT]
2020-05-26 Fixed spacing of simon says face plate
    [Simon says face plate.SLDPRT]
2020-05-26 Added part for a button holder for memory module
    [TRIANGLE.SLDPRT]
2020-05-27 Swaped analogRead to adc.readADC
    [basicWires.ino]
2020-05-27 Swapped buttons 3 and 4
    [memory.ino]
2020-05-27 Replace simon says buttons to switches
    [allModules.sch]
2020-05-28 Renamed simon says buttons
    [allModules.sch]
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2020-05-29 Swapped 2 pins on MAX6954 IC for readability
    [allModules.sch]
2020-06-01 Fixed button module having hardcoded config
    [button.ino]
2020-06-01 Fixed speaker pin being wrong
    [mainModule.ino]
2020-06-01 Goal can no longer appear on marker locations
    [mazeModule.ino]
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2020-06-06 Fixed wires module
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2020-06-07 Fixed delay when retrieving time left
    [button.ino]
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2020-06-08 Now actually displays 0's on loose
    [mainModule.ino]
2020-06-08 Fixed issue with goal always being at 0, 0
    [mazeModule.ino]
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2020-06-09 Fixed part being different from manual
    [memory.ino]
2020-06-11 Added MCP23017 to schematic
    [allModules.sch]
2020-06-11 Added resistors to indicator led's
    [allModules.sch]
2020-06-14 Fixed error on no batteries
    [configModule.ino]
